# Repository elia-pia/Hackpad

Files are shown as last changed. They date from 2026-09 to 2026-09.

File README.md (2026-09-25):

    _   _            _                    _ 
    | | | | __ _  ___| | ___ __   __ _  __| |
    | |_| |/ _` |/ __| |/ / '_ \ / _` |/ _` |
    |  _  | (_| | (__|   <| |_) | (_| | (_| |
    |_| |_|\__,_|\___|_|\_\ .__/ \__,_|\__,_|
                          |_|     

A 3-key macropad, built for Hack Club's Stardance Challenge.

## Gallery
 
| PCB | Final CAD |
| --- | --- |
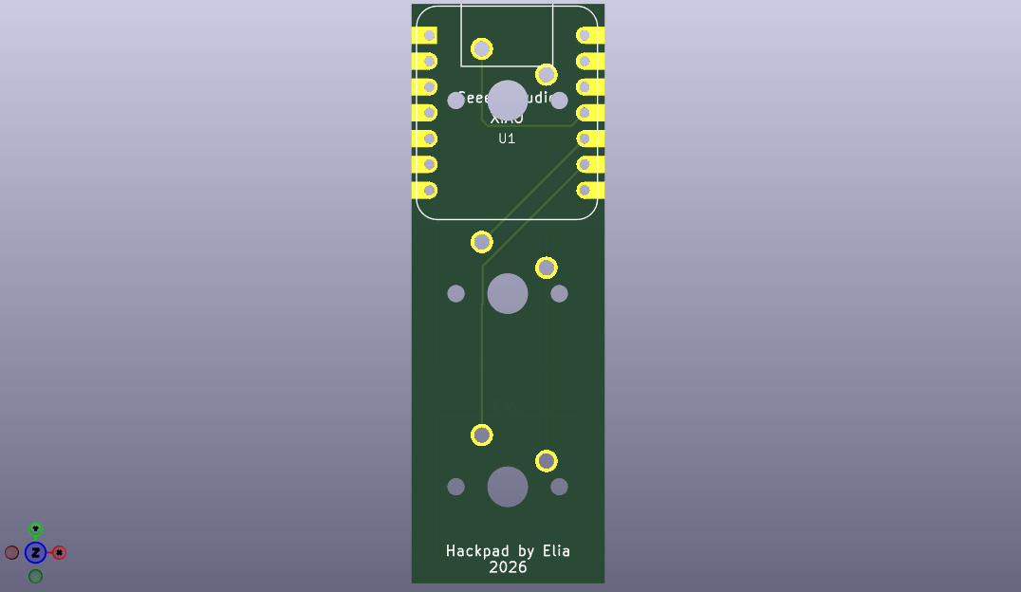
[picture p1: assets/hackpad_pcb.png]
Hackpad PCB
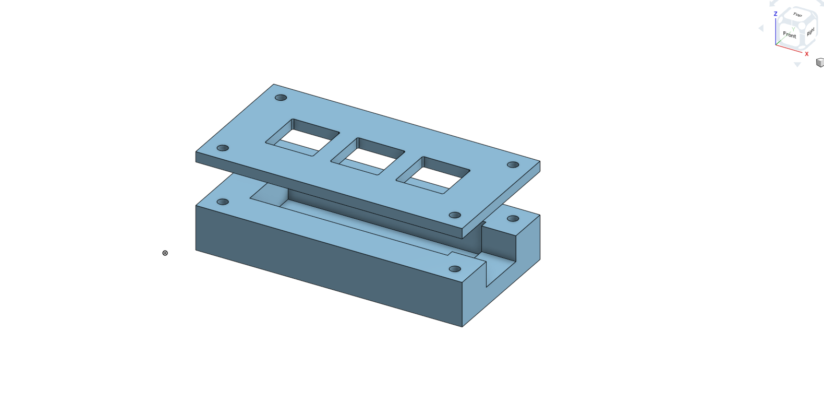
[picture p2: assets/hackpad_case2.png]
Hackpad case
|  |  |

## What's in this repo
 
- `hackpad.kicad_pro`, `hackpad.kicad_sch`, `hackpad.kicad_pcb` — KiCad project, schematic, and PCB layout
- `enclosure.stl` / `case_lid.stl` — 3D-printable case files
- `hackpad_case.png`
## Building it
 
1. Open `hackpad.kicad_pro` in [KiCad](https://www.kicad.org/) to view or edit the schematic and PCB.
2. Order the PCB from JLCPCB of choice using the KiCad project files.
3. 3D print `enclosure.stl` and `case_lid.stl`.
4. Assemble the PCB into the printed case
 
## What is this?
 
my Hackpad is a tiny 3-switch macro keyboard made of three Cherry MX–compatible switches and an RP2040 microcontroller, running my custom QMK firmware so every key can be remapped to whatever shortcut, media key, or macro you want.
 
## Gallery
 
| PCB (KiCad layout) | PCB (3D render) | Case (final CAD) |
| --- | --- | --- |
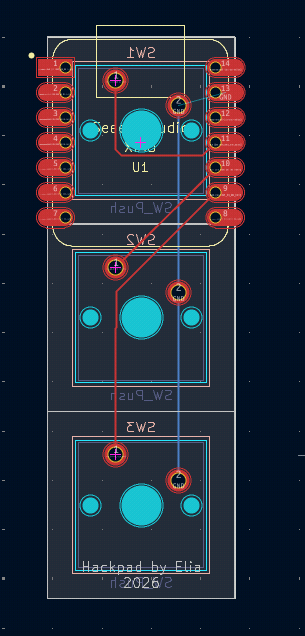
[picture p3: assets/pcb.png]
PCB layout in KiCad
|  | 3D render of the PCB | Final case render |

## How it all fits together
 
Assembly diagram
 
The PCB will fit into the case, with the three switches poking up through the matching cutouts in the lid. The lid then closes over the top with two screws.
 
## Bill of materials
 
| Qty | Part | Notes |
| --- | --- | --- |
| 1 | Seeed Studio XIAO RP2040 (`U1`) | The microcontroller — footprint `XIAO-Generic-Hybrid-14P-2.54-21X17.8MM` |
| 3 | Cherry MX–compatible switches (`SW1`–`SW3`) | Footprint `Button_Switch_Keyboard:SW_Cherry_MX_1.00u_PCB` |
| 1 | Custom PCB | Fabricate from `production/gerbers.zip` |
| 1 | 3D-printed enclosure | `production/enclosure.stl` |
| 1 | 3D-printed lid | `production/case_lid.stl` |
| 4 | Mounting screws |
| 3 | Keycaps (optional) | Any Cherry MX–compatible keycap should fit |
| 1 | USB-C cable |
 
## What's in this repo
 
- `pcb/` — KiCad project, schematic, and PCB layout
- `cad/` — STEP files for the enclosure and lid
- `production/` — ready-to-use files: STLs for printing, gerbers for pcb, and a pre-compiled firmware `.uf2`
- `firmware/` — QMK firmware source and keymap
- `assets/` — fotos and diagrams used in this README
## Building it
 
1. **Get the PCB made** — send `production/gerbers.zip` to a fab, or open `pcb/hackpad.kicad_pro` in [KiCad](https://www.kicad.org/) if you want to modify the design first.
2. **Print the case** — print `production/enclosure.stl` and `production/case_lid.stl` (or the STEP files in `cad/` if you're adapting the shape).
3. **Flash the firmware** — drag `production/simple_hackpad_default.uf2` onto the RP2040 in bootloader mode, or build it yourself from `firmware/` with QMK if you want to change the keymap first.
4. **Assemble** — solder the switches and XIAO to the PCB, drop it into the case, and close up the lid as shown above.

also a big thanks to the Stardance team

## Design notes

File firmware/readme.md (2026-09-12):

# simple_hackpad

simple_hackpad

*A short description of the keyboard/project*

* Keyboard Maintainer: [Elia Piagentini](https://github.com/elia-pia)
* Hardware Supported: *The PCBs, controllers supported*
* Hardware Availability: *Links to where you can find this hardware*

Make example for this keyboard (after setting up your build environment):

    make simple_hackpad:default

Flashing example for this keyboard:

    make simple_hackpad:default:flash

See the [build environment setup](https://docs.qmk.fm/#/getting_started_build_tools) and the [make instructions](https://docs.qmk.fm/#/getting_started_make_guide) for more information. Brand new to QMK? Start with our [Complete Newbs Guide](https://docs.qmk.fm/#/newbs).

## Bootloader

Enter the bootloader in 3 ways:

* **Bootmagic reset**: Hold down the key at (0,0) in the matrix (usually the top left key or Escape) and plug in the keyboard
* **Physical reset button**: Briefly press the button on the back of the PCB - some may have pads you must short instead
* **Keycode in layout**: Press the key mapped to `QK_BOOT` if it is available

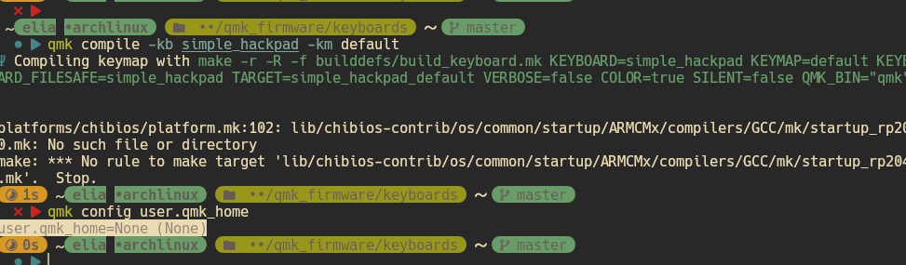
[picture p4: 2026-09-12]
assets/firmware3.png

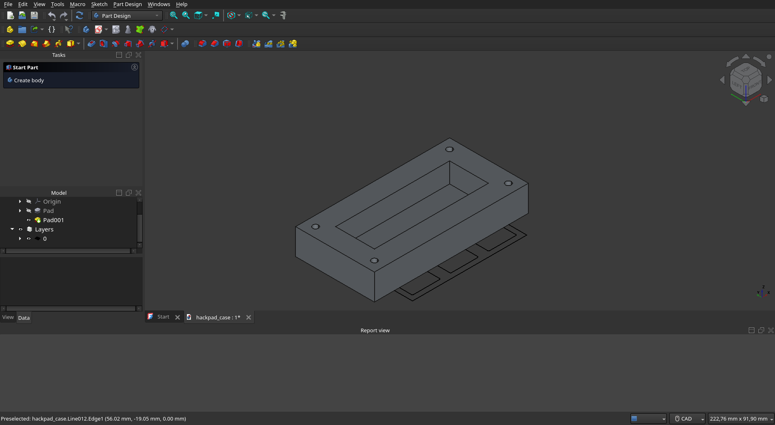
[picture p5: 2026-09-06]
assets/hackpad_case.png

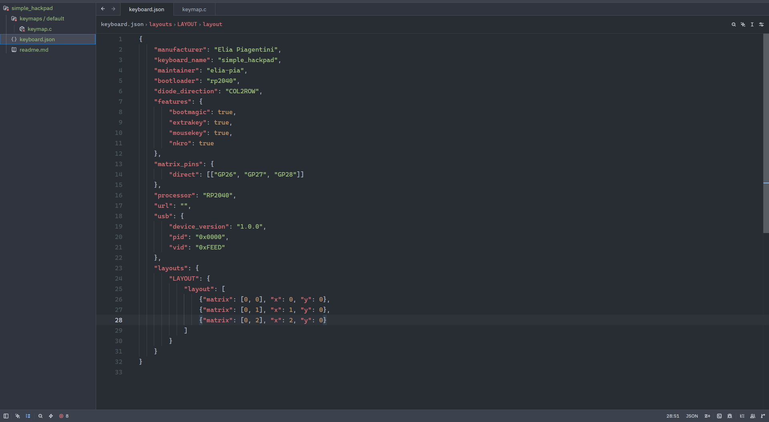
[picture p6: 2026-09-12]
assets/firmware2.png

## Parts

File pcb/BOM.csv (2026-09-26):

Qty | Component | Reference | Notes
1 | Seeed Studio XIAO RP2040 | U1 | Microcontroller; footprint XIAO-Generic-Hybrid-14P-2.54-21X17.8MM
3 | Cherry MX-compatible switch | SW1, SW2, SW3 | Footprint Button_Switch_Keyboard:SW_Cherry_MX_1.00u_PCB
1 | Custom PCB |  | Fabricate from production/gerbers.zip
1 | 3D-printed enclosure |  | production/enclosure.stl
1 | 3D-printed lid |  | production/case_lid.stl
4 | Mounting screw |  | Size not specified in project files; match to the case's screw posts
3 | Keycap (optional) |  | Any Cherry MX-compatible keycap fits
1 | USB-C cable |  | To flash firmware and connect the finished pad to a computer

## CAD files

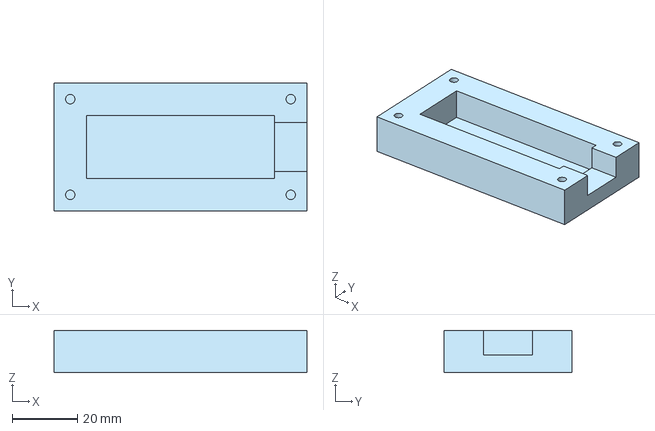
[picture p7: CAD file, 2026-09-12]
production/enclosure.step
77.8 x 39.4 x 13.0 mm

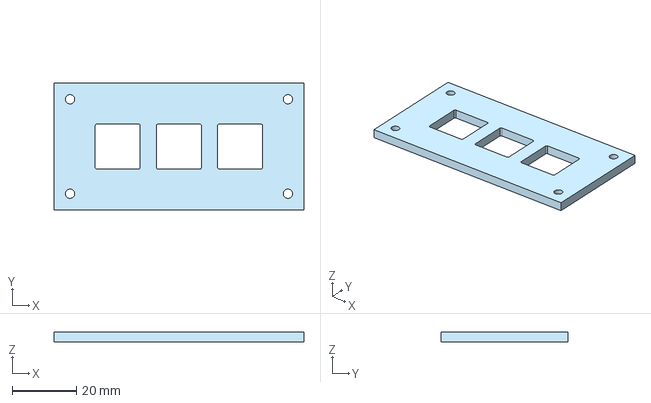
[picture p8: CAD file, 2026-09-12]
production/lid.step
77.8 x 39.4 x 3.00 mm

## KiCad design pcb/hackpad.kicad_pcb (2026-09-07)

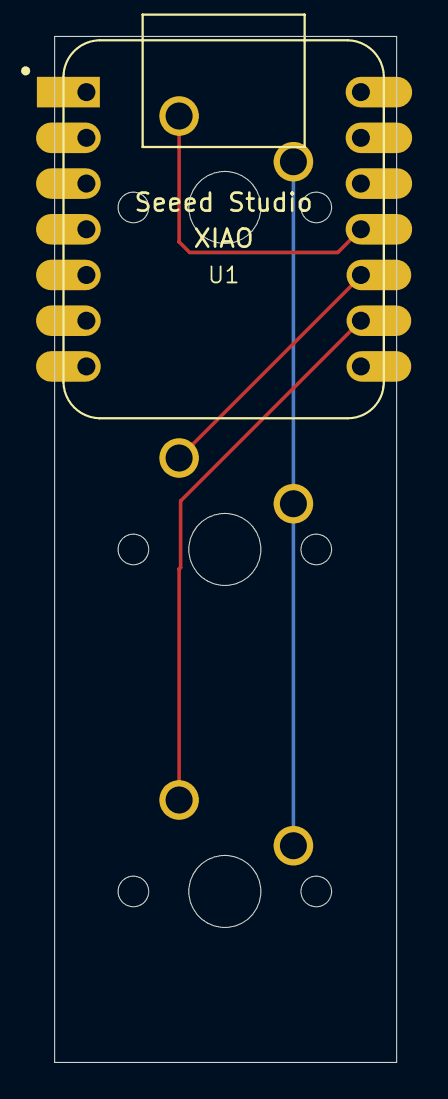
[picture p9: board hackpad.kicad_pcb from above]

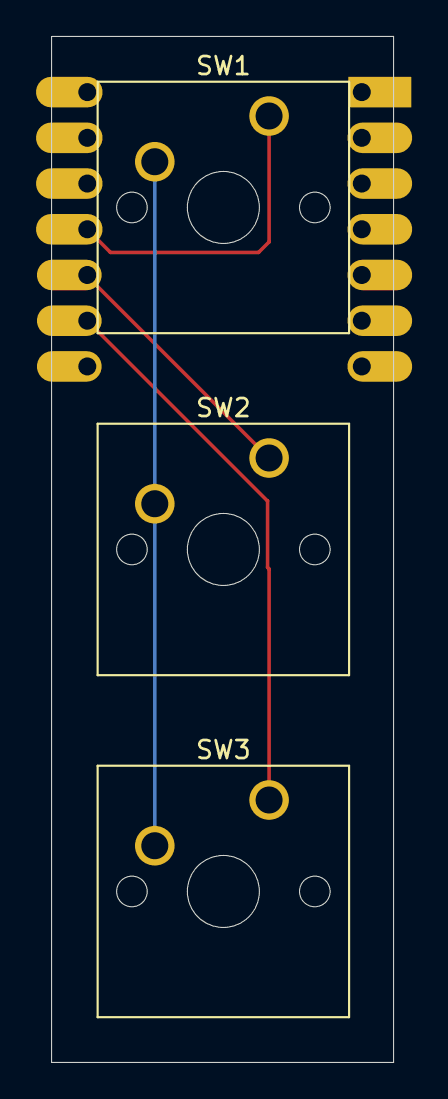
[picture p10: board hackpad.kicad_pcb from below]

Board: 2 copper layers, 19.0 x 57.0 mm, 4 parts (3 on the bottom side), 4 nets.

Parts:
SW1, SW2, SW3: SW_Push; SW_Cherry_MX_1.00u_PCB
U1: MOUDLE-SEEEDUINO-XIAO; XIAO-Generic-Hybrid-14P-2.54-21X17.8MM

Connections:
GND: SW1.2, SW2.2, SW3.2, U1.13 (GND)
unnamed: SW2.1, U1.10 (PA5_A9_D9_MISO)
unnamed: SW1.1, U1.11 (PA6_A10_D10_MOSI)
unnamed: SW3.1, U1.9 (PA7_A8_D8_SCK)

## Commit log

2026-09-06 first commit of my hackpad
    added:
    pcb design files,
    case 3d models (WIP).
    [hackpad.kicad_pcb, hackpad.kicad_sch, hackpad_case.FCStd]
2026-09-07 added final case files
    [case_lid.stl, enclosure.stl, hackpad.kicad_pcb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]
2026-09-12 cleaned up and should be all
    [case_lid.stl, enclosure.step, enclosure.stl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]
2026-09-14 fixing some files
    [case_lid.stl, enclosure.step, enclosure.stl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]
2026-09-16 addede BOM.csv (Bill Of Materials)
    [hackpad.csv]
2026-09-16 corrected filenames
    [BOM.csv]
